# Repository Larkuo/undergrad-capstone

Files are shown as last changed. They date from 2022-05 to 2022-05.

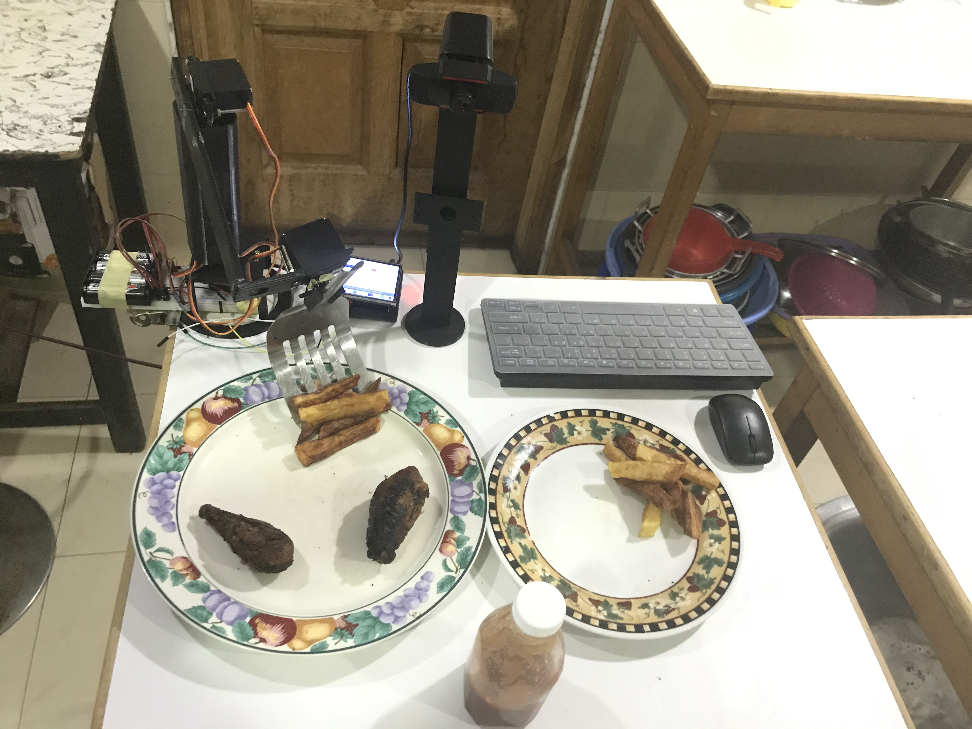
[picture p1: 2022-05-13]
Prototyping/Media/assembly_image.jpg

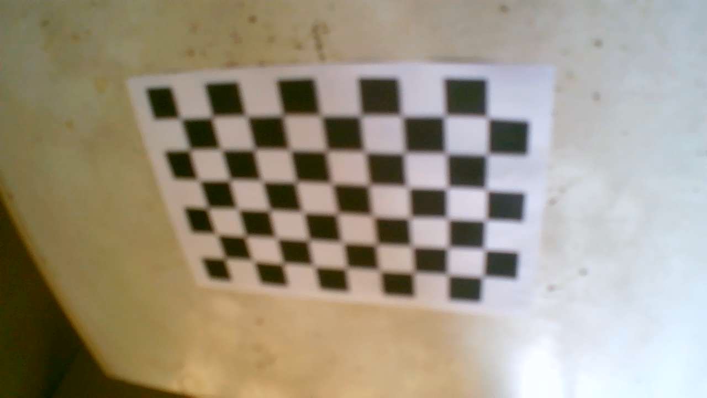
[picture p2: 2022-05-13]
Prototyping/Scripts/camera calibration images/WIN_20220427_16_50_19_Pro.jpg

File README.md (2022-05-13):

ENG401 - Engineering Capstone Project Seminar 2021-2022
============================

> This is a repository containing all my capstone files organized in the following folders.

├── .

    ├── README.md

    ├── Design                  # All files relevant to the design part of my project 

    │   ├── CAD Model           # Images & STL files from Onshape

    │   ├── Circuit Design      # Images & .fzz files from Fritzing

    ├── Model Training          # Files from the model training part of my project 

    │   ├── Data                # Images & Annotation files from LabelImg

            ├── Train           # 800 training images & corresponding annotaion files

            ├── Validate        # 200 validation images & corresponding annotaion files   

    │   ├── Notebooks           # All python notebooks used for training

    │   ├── Models              # All tflite models from training

    ├── Protoyping              

            ├── Scripts         # All python scripts used in the project

            ├── Media           # Prototype image & Demo video

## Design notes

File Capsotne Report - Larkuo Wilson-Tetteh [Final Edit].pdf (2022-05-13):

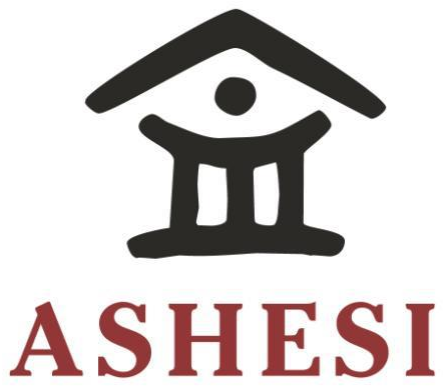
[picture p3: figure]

# ASHESI UNIVERSITY

DESIGN OF A LOW-COST ROBOTIC MANIPULATOR FOR FOOD

HANDLING

CAPSTONE PROJECT

### B.Sc. Computer Engineering

Larkuo Wilson-Tetteh

2022

ASHESI UNIVERSITY

DESIGN OF A LOW-COST ROBOTIC MANIPULATOR FOR FOOD

HANDLING

CAPSTONE PROJECT

### Capstone Project submitted to the Department of Engineering, Ashesi

### University College in partial fulfilment of the requirements for the award of

Bachelor of Science degree in Computer Engineering.

Larkuo Wilson-Tetteh

2022

i

DECLARATION

I hereby declare that this capstone is the result of my own original work and that no part of

it has been presented for another degree in this university or elsewhere.

Candidate’s Signature:

Candidate’s Name:

Larkuo Wilson-Tetteh

Date:

28/04/2022

I hereby declare that preparation and presentation of this capstone were supervised in

accordance with the guidelines on supervision of capstone laid down by Ashesi University

College.

Supervisor’s Signature:

Supervisor’s Name:

Dr. Stephen K. Armah

Date:

ii

Acknowledgements

To my supervisor, Dr. Stephen K. Armah whose encouragement and academic advice

helped me undertake this project.

iii

Abstract

Industry 4.0 improved production processes for many manufacturing processes however,

this change was not as pronounced in many service industries including the food service

industry. Considering the high cost of implementing technologies such as robotics, edge

computing and machine learning there are not many options for establishments such as

restaurants and fast-food places to also implement various parts of Industry 4.0 into their

services. With the growing consumer demand especially regarding dietary differences, it

has become more important for food service establishments to make their processes smarter

to keep up with the demand.

In this project, a low-cost, computer vision-controlled robotic manipulator is implemented

to assemble a custom plate of food without human assistance. This was achieved by

collecting and annotating 1000 images as well as training an object detection model with no

less than 90% average precision for each of the possible classes as well as an average recall

of 94.45% where there were no more than 10 objects in the image frame. A 3D printed

robotic manipulator was then assembled with servo motors, a Raspberry Pi, and a low-cost

web camera and the model, together with python scripts were then used to make real-time

detections while picking and dropping the food items from one plate to another within the

manipulator’s workspace.

iv

## Table of Contents

v

Chapter 1: Introduction

The food industry has not seen much adaptation of Industry 4.0 in its operations. With the ever-

increasing demand and variance in dietary preferences, it has become more important that food

service establishments begin to explore options to integrate smart technologies into their

kitchens. In this chapter of the project, a detailed background will be discussed followed by a

problem definition and a proposed solution. Finally, the objectives of the project will be

highlighted.

### 1.1 Background

Industry is an essential part of the global economy that produces goods through

mechanized and often automated processes. Industrialization has experienced multiple

technological cycles that enhanced processes throughout history with the most recent being

Industry 4.0. This cycle of the industrial revolution is changing the way industries manufacture

their products with the introduction of Internet of Things (IoT), Edge computing, Robotics,

Artificial Intelligence (AI) and machine learning into their manufacturing processes [1].

Essentially, Industry 4.0 describes the advent of smart factories which have predictive

maintenance, quicker responses, and more autonomously intelligent manufacturing

procedures.

While many industries have integrated many parts of Industry 4.0 into their operations,

the food production industry especially in customer-facing establishments has not seen much

change with regards to making their processes smarter. Commercial kitchens are one of such

customer-facing establishments and form a significant part of the industry. In commercial

kitchens, large quantities of are cooked and served in real-time daily and such kitchens are

typically found in places such as hotel restaurants, cafeterias, and fast-food establishments.

Like many other industries, commercial kitchens are designed to produce food quickly and repetitively without jeopardizing food quality and customer satisfaction.

### 1.2 Problem Definition

Commercial kitchens do a great job at serving multiple customers, these services

involve manned activities which are prone to error and inefficiency especially when exhaustion

sets in. Considering the cost of implementing traditional industrial automation and the growing

human population as well as an increasing variance in the dietary preferences of food

consumers [2] it has become more complex to use traditional industrial technologies to

automate processes in commercial kitchens unlike with other industries whose processes do

not involve as many customizations.

### 1.3 Proposed Solution

By means of smart, low-cost, and versatile technology commercial kitchens can begin

to implement parts of Industry 4.0 in their establishments to help them keep up with increasing

demand and ever-changing custom dietary requirements of the customers they serve. For this

project, the proposed solution would be to design and build an affordable robotic manipulator

that is smart and can identify different types of food items as well as assemble customizable

plates for customers.

### 1.4 Objectives 1.41 Main Objective

With the increasing demand placed on commercial kitchens and the need to keep up

with competitors, the aim of this project is to design and prototype an autonomous low-cost

robot that can assemble a meal with minimal human input. To reduce the need for human

interference or supervision, another important part of this project is to make the robot smart.

### 1.4.2 Specific Objectives

After establishing the primary objective of the project, which is to design a smart, low-cost robot to assemble a meal, some more specific objectives of this project are mentioned

subsequently.

1. Design a robotic arm that can pick and drop cooked food without significantly

altering the organoleptic properties of the food.

2. Design a robotic arm whose workspace is suitable for a kitchen workstation.
3. Train an object detection model that can correctly identify different food items and

kitchen utensils as well as their XYZ-positions in the workspace in real-time.

Chapter 2: Literature Review & Related Work

An important part of the engineering design process is reviewing existing literature and

projects to draw inspiration and identify gaps. In this chapter of the project, manipulator

dynamics will be studied along with important concepts in computer vision and object detection

such as image labelling and model evaluation metrics. Subsequently, similar existing projects

and papers that have been published will be mentioned to draw some inspiration for the solution

and identify some gaps.

### 2.1 Literature Review

### 2.1.1 Manipulator Dynamics

A manipulator’s kinematics can be described in two ways, forward kinematics, and

inverse kinematics. Forward kinematics are used to describe the position and orientation of the

robot’s end effector based on the angular displacement or velocity inputs from each joint of the

robot. Whereas inverse kinematics are used to calculate the value each joint variable given the

specific position and orientation of the end effector [3]. The Denavit-Hartenberg (D-H) method

[4] is a standard method used to derive the kinematics for a robotic manipulator for all robot

configurations and will be used in this paper.

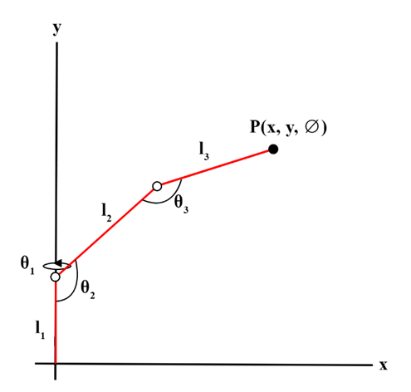
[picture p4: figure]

Figure 2.1: Labeled diagram of joint angles, link lengths, and end effector positions for a robotic manipulator

with 3 degrees of freedom.

From Figure 2.1,

P (x, y, ∅) = x, y position of end effector witℎ orentation ∅

li = lengtℎ of link i

θi = angle of rotation θ of link i

And, given a robot with 3 degrees of freedom (3-dof), like in figure 2.1, the forward kinematics

are,

x = l1cos θ1 + l2cos(θ1 + θ2

) + l3cos(θ1 + θ2 + θ3

) − − − (1)

y = l1 sin θ1 + l2 sin(θ1 + θ2) + l3 sin(θ1 + θ2 + θ3) − − − (2)

∅ = θ1 + θ2 + θ3 − − − (3)

While the inverse kinematics are,

θ1 = tan⁻¹

y
x

− − − (4)

θ2 = cos⁻¹

x

2 + y

2 + z

2 − l1

2
l2

2
2l1l2

− − − (5)

θ3 = sin⁻¹

∅
√x
2 + y

2 + ∅²

+ tan⁻¹

l2 sin θ2
l1 + l2 cos θ2

− − − (6)

### 2.1.2 Object Detection & Position Calculation

Object detection/recognition is a type of computer vision task where instances of

objects in an image or video frame are located [5] with details such as a bounding box, scale

of the object in the frame and the score of the prediction which describes how sure the model

is about the prediction. Algorithms that perform object detection tasks are often a result of

using machine learning to train the algorithm to detect the desired objects.

Measuring the performance of an object detection model is important before the model

is deployed into an application. Some performance metrics used to evaluate object detection

models include, Intersection over Union (IoU), Precision and Recall.

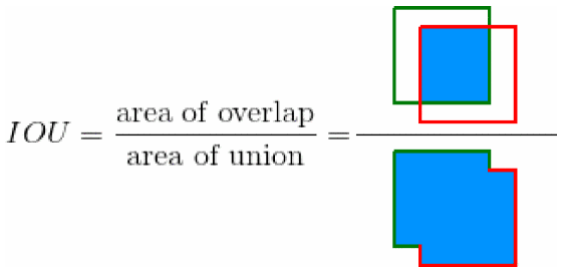
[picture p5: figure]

Figure 2.2: A graphical representation of the Intersection over Union (IoU) metric [6].

IoU is a metric that “measures the overlapping area between the predicted bounding box

and the ground-truth/actual bounding box divided the area of the union between them” as [6]

as demonstrated in Figure 2.2. Precision describes a model’s ability to only make correct

predictions. These include true positives and true negatives; true positives refer to correct

bound box detections where there are identifiable objects in the image/video frame while true

negatives refer to the absence of bound boxes where there are no identifiable objects in frame.

The metric recall assesses the model’s ability to find all existing bound boxes. [6].

### 2.2 Related Work & Gaps

2.2.1 Interpreting and Executing Recipes with a Cooking Robot (Bollini, Tellex,

Thompson, Roy & Rus)

In their paper “Interpreting and Executing Recipes with a Cooking Robot” Bollini,

Tellex, Thompson, Roy and Rus implemented a robot that reads plain text recipes for simple

dishes and executes them; one recipe at a time [7]. With the assumption that the robot had

access to a model of the kitchen, a set of labeled ingredients and the locations of tools such as a whisk or an oven the robot was initialized with a set of ingredients in labeled bowls laid out

on a table. It was also initialized with a set of natural language instructions describing how to

use the ingredients laid out to cook a specified dish. For instance, a group of ingredients which

include flour, butter, sugar, and eggs may be initialized together with instructions such as “Add

sugar and beat to a cream”. The robot also has a repertoire of basic actions which include

pouring and mixing ingredients. After parsing the plain text recipe to the robot, it performs the

inferred actions associated to the instruction using the PR2 Robot Manipulation Platform.

The PR2 Robot Manipulation Platform is a robot that was built by researchers at Willow

Garage and first released in February 2009 and made available for purchase in September the

next year; 2010 captured in Figure 2.3. It has two manipulators and runs on ROS (Robot

Operating System) which is an open-source robotics framework that allows communications,

message passing, remote procedure calls, among many other components [8].

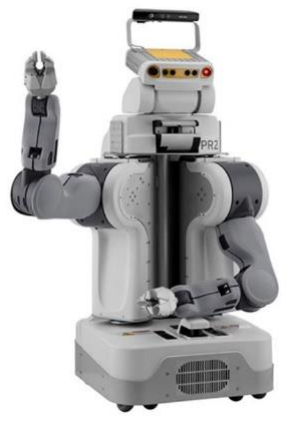
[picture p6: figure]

Figure 2.3: The Willow Garage PR2 Personal Robot 2 mobile manipulation platform used for the BakeBot

system [8].

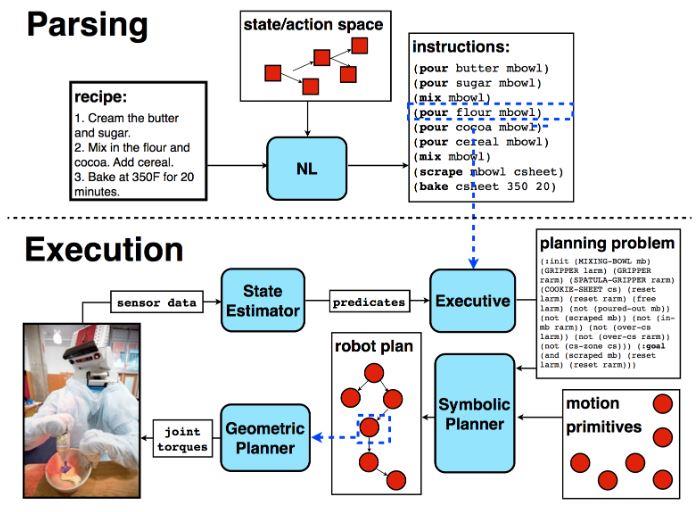
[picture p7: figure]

Figure 2.4: Architecture of the Bollini et al. BakeBot System that shows the progression from NL processing of

the plain text recipe to executing the task [7].

A graphical representation of the architecture of the cooking robot system by Bollini et

al. is shown in Figure 2.4.

To test their approach, the researchers experimented with their language processing

system and a database of 60 recipes to test instruction inference and a real-world demonstration

in a kitchen which had two work surfaces to test execution. After doing the real-world

experimentation 27 times, the researchers found that their defined basic motions enabled a

variety of recipes to be executed. They also discovered that their natural language system

worked well because for most instructions, it correctly inferred the corresponding action.

However, they also recorded an average runtime of 142 minutes from start to finish which was

far slower than the average human. In their tests, they also noted that the robot made many

more failures such as the end effector slipping of the oven door halfway through the opening

procedures.

An identifiable gap in Bollini et al.’s research paper is that the design focused heavily

on natural language processing. This resulted in the partial neglect of the design for the

hardware especially the end effector of the robot manipulators which resulted in mistakes. The

design and experimentation did not consider the different textures, hardness and sizes of the tools and ingredients that were used for the demonstration which affected the end effector’s

performance. Finally, the experiment did not mention how the robot adhered to kitchen hygiene

standards. Thus, the safety of the food for human consumption is not assessed.

### 2.2.2 A Methodology for the Selection for Industrial Robots in Food Handling. (Farah

Bader & Shahin Rahimifard)

Another paper that explored the robot selection process for the food industry is “A

methodology for the selection of industrial robots in food handling” by Bader and Rahimifard

[2]. The aim of this paper’s research was to discover a design methodology that makes it easier

for engineers and producers in the food industry to design flexible robots and suitable end

effectors that can handle food appropriately based on the foodstuff in the application. The

researchers also aimed at ensuring that the design process ensured that the organoleptic

properties of all foodstuffs handled by the selected robot was preserved. Bader and

Rahinmifard named their four-step process of selecting the appropriate robot for food handling

Food Industrial Robot Methodology (FIRM).

Step one of FIRM involves defining foodstuff by type and condition as well as the state

of the foodstuff under consideration.

- Foodstuff Type: Meat & Poultry, Seafoods, Fruits & Vegetables, Baked Goods

& Confectionaries, Dairy Derivatives or Others (e.g., grain like rice and powdered spices)

- Foodstuff Condition: Raw, Cooked or Frozen
- Foodstuff State: Whole or Segmented

Step two of the selection method further classifies food items by rigidity how hard or

soft the foodstuff is and deformability how easy it is to change visual and textural properties

the foodstuff when force is applied by the robot. In both classifications, foodstuff can be

described as follows.

- Deformability: Deformable or Non-Deformable
- Rigidity: Rigid, Semi-Rigid or Non-Rigid

These two classifications of foodstuff in this step creates six distinct groups which made

selection of the type of robot and suitable end effector easier.

Overall, this project excelled at creating a standard methodology for engineers who in

the future will work on industrial robots for food. However, a gap of this paper was that a

limited group of options were selected as options for handling the food. Again, though an

example of the FIRM procedure was demonstrated in the paper, the was no documented test to

give an idea of how effective this method is in real world food handling applications.

Chapter 3: Design

In this chapter of the project, the primary of objective will be to design an effective

food handling robotic manipulator and end effector that correctly identifies, locates, and picks

up food items to assemble a meal. For proof of concept, this project will focus on assembling

a plate of potato fries with a piece or more of chicken as well as a portion of ketchup where

requested.

### 3.1 Requirements

To achieve the objectives of this project, there are some functional and technical

requirements the manipulator needs to satisfy.

Functional Requirements:

1. A camera to enable computer vision-based object detection.
2. At least 3 degrees of freedom (3-dof) in the robotic arm to enable easy movement

in the workspace.

Technical Requirements:

3. An object detection model with at least 90% Average precision (AP) for each item

that needs to be detected.

4. An object detection model with at least 90% Average recall when there is a

maximum of 10 objects in the image/video frame.

### 3.2 Material Selection

In this section of the design chapter, materials including motors, a microcontroller and

a camera will be selected using weighted Pugh Matrixes which feature a datum as well as

comparison options for each part of the proposed solution.

### 3.2.1 Motors

In considering motor options for the manipulator, some significant requirements

included cost, feedback for closed loop control, power consumption, precision, torque, and

accuracy. These requirements are also weighted in the table below because requirements such

as cost, and feedback are more relevant to the project because the robotic manipulator needs to

be low cost and allow feedback for controls. However, requirements such as torque are

weighted less because all food items listed in the design overview weight less than 1 kilogram

(kg) since they will each be handled one at a time. The datum for this matrix was a DC motor

with the options being a servo motor and a stepper motor as shown in Table 3.1.

Table 3.1: Pugh matrix for the selection of motors with DC motor as datum

Criteria | Weight | DC Motor | Servo Motor | Stepper Motor
Low Cost | 3 | 0 | 0 | -
Feedback/Control | 4 | 0 | + | +
Power Consumption | 2 | 0 | 0 | -
Precision | 3 | 0 | + | +
Torque | 4 | 0 | + | +
Accuracy | 4 | 0 | + | +
Continuous Rotation | 5 | 0 | + | +
Total | | 0 | +20 | +15

In this selection, a servo motor was selected because like the datum, it is low cost

however, unlike the DC motor, it allows feedback and control without the need for an external

encoder. Finally, the servo motor had a higher score because it is accurate even at high speeds.

### 3.2.2 Manipulator Material

With the selection of the material most suitable for the manipulator, the criteria is focused on ease of cleaning, food safety, cost, heat resistance, durability, and humidity

resistance. This is because in typical kitchens where a solution of this type will be implemented,

there is high heat and humidity which are factors that cause corrosion and wear in some

materials. The datum for this selection is stainless steel; a material often used for kitchen

utensils and the options are aluminium, copper and polylactic acid (PLA).

Table 3.2: Pugh matrix for the selection of the manipulator material with stainless steel as datum

Criteria | Weight | Stainless Steel | Copper | Aluminium | Polylactic Acid (PLA)
Low Cost | 3 | 0 | - | + | +
Ease of cleaning | 3 | 0 | 0 | 0 | -
Food Safety | 5 | 0 | - | 0 | 0
Heat Resistance | 4 | 0 | - | - | +
Durability | 4 | 0 | - | - | -
Humidity Resistance | 4 | 0 | - | - | +
Total | | 0 | -20 | -14 | +4

From Table 3.2, the material with the highest score is polylactic acid (PLA) which was

scored higher than the other materials because of its low cost and food safety. Again, it is less

susceptible to corrosion in humid environments and does not conduct heat well which is

important for this project.

### 3.2.3 Microcontroller

For the selection of a microcontroller for this project, processing power was a very

important criteria because of the use of a camera in the design. This is because implementing

vision algorithms especially in real-time is computation heavy. Again, cost, power

consumption, and having enough GPIO pins were important to consider especially because of the motors required for this project.

Table 3.3: Pugh matrix for the selection of a microcontroller with Arduino Nano as datum

Criteria | Weight | Arduino Nano | Raspberry Pi 4 | ESP 32 | Tetrix Prizm
Low Cost | 3 | 0 | - | + | -
Processing Power | 5 | 0 | + | - | 0
GPIO Access | 5 | 0 | + | - | +
Power Consumption | 3 | 0 | - | + | -
Total | | 0 | +4 | -4 | -1

The Raspberry Pi 4 was selected in Table 3.1 because though it is slightly more

expensive than the datum, this microcontroller has USB ports compatible with many cameras.

The Raspberry Pi also has the best processing power compared to the datum and the other

options. This makes it the most appropriate for a computation heavy application such as object

detection. Again, the Raspberry Pi has enough pins to house all other components required for

the robotic manipulator.

### 3.2.4 Camera

For the selection of an appropriate camera, resolution, cost, field of view imaging rate

and suitable interconnect protocols were important criteria. Interconnect or interface standards

for cameras can be described as a codified identity for how a camera is connected to a computer

or micro-controller to allow easier and more effective use of vision as a technology. With this

selection, the datum was the Raspberry Pi Camera v2 with the rest of the selection options

being USB 2.0 camera as well as the Raspberry Pi NOIR camera. The criteria and the options

are shown in the Table 3.4.

Table 3.4: Pugh matrix for the selection of a camera with Raspberry Pi Camera v2 as datum

Criteria | Weight | Raspberry Pi Camera v2 | USB 2.0 Camera | Raspberry Pi NOIR Camera
Low Cost | 3 | 0 | + | 0
Interface Standard | 5 | 0 | + | 0
Power Consumption | 3 | 0 | - | 0
Field of View | 4 | 0 | + | 0
Resolution | 4 | 0 | 0 | 0
Imaging Rate | 4 | 0 | + | 0
Speed | 5 | 0 | + | 0
Total | | 0 | +18 | 0

Ultimately, the USB 2.0 camera was selected because it cost less, had a more common

interface standard as well as the camera standard having a larger bandwidth and wider range

for its field of view. Again, the selected camera is compatible with the selected microcontroller;

Raspberry Pi 4.

### 3.3 CAD Model

To model the movements of the manipulator prior to building the manipulator, a 3D

model was created using Onshape; a web-based computer aided design (CAD) software. The

model is a robotic manipulator with 3 motors: one for each degree of freedom. See Figure 3.1

and Figure 3.2.

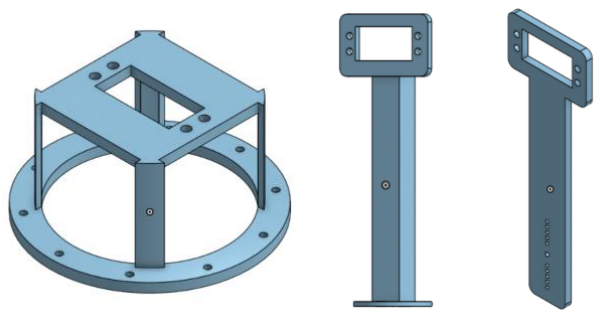
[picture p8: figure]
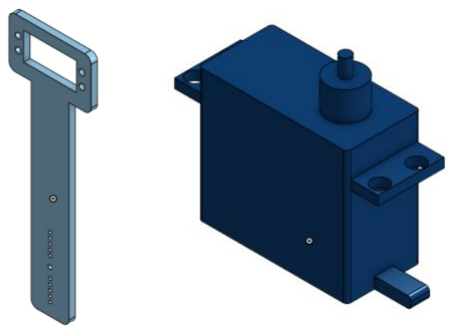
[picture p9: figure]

(a) | (b) | (c) | (d) | (e)

Figure 3.1: Diagram of parts for the 3D model of the manipulator (a) Link 1 (b) Link 2 (c) Link 3 (d) Base (e)

| | Servo Motor

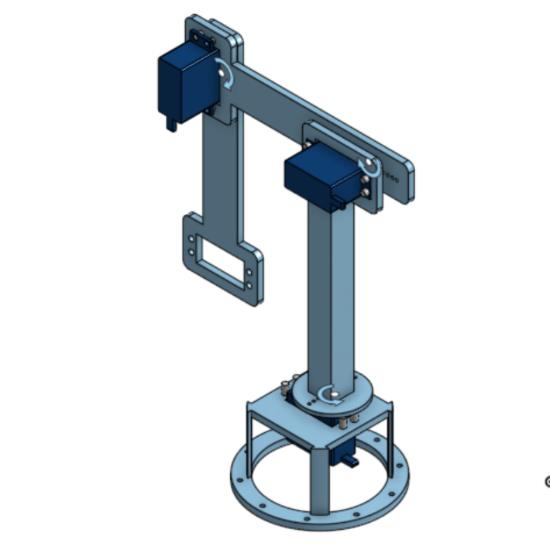
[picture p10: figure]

Figure 3.2: Image of manipulator assembly CAD model

### 3.4 Electrical Circuit

Figure 3.3 shows how the electrical and electronics parts of the robot manipulator will

be connected. The connections include 4 servo motors, a Raspberry Pi, a USB camera plugged

into the Raspberry Pi and 2 power supplies; one for the Raspberry Pi and another for the servo

motors.

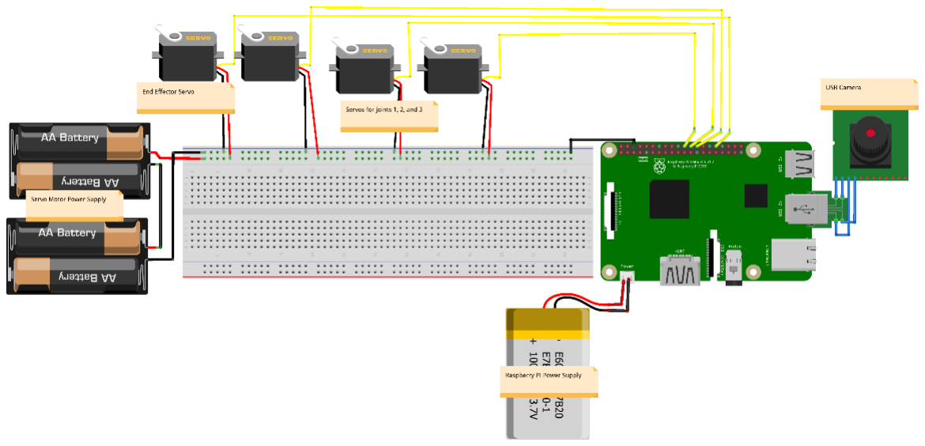
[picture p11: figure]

Figure 3.3: Circuit diagram of electronic connections for a 3 DOF manipulator in Fritzing

Chapter 4: Data Collection & Model Training

In this chapter of the project, details about collecting the images, processing the images,

and labelling the images will be discussed. Setting up the training environment and other

required details as well as the process of training the object detection model will be highlighted.

### 4.1 Image Collection & Labeling

### 4.1.1. Image Collection

One of the most important parts of training any machine learning model is the process

of collecting the data. For this project, a USB camera was connected to a computer at a height,

30 cm from the kitchen worktable as shown in Figure 4.1.

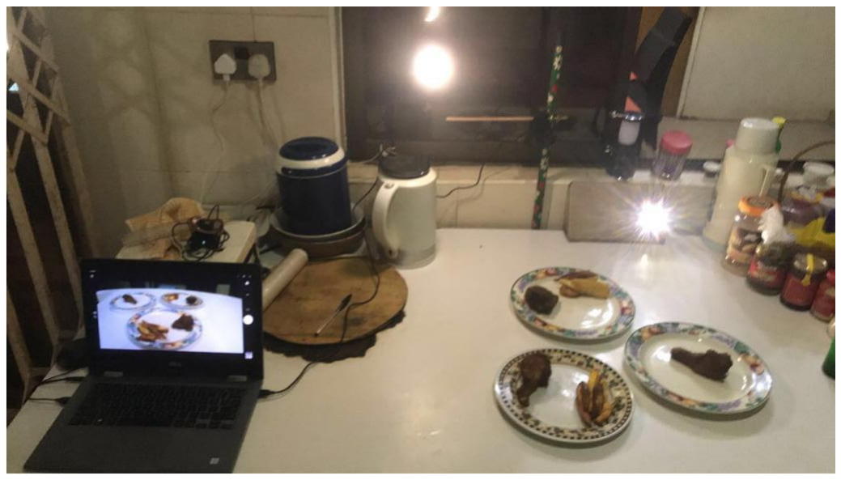
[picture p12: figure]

Figure 4.1: An image of the data collection setup with the laptop and camera

With the computer and camera setup, 1000 images were taken: each with a resolution

of 640 pixels x 320 pixels. Images were taken in batches of 5 with variations which included

changing the orientation of items, reducing the amount of light, and moving objects in and out

of the image frame. Some samples of the images are shown in Figure 4.2.

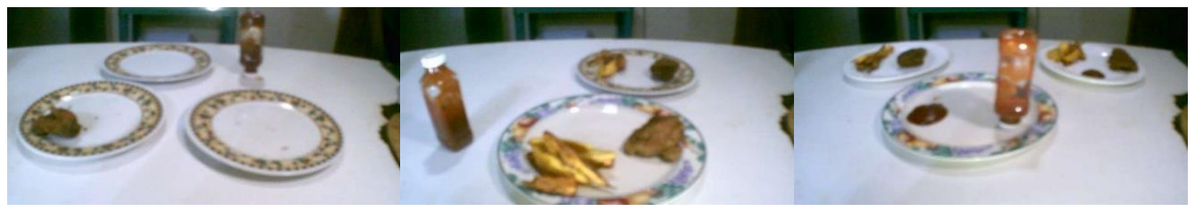
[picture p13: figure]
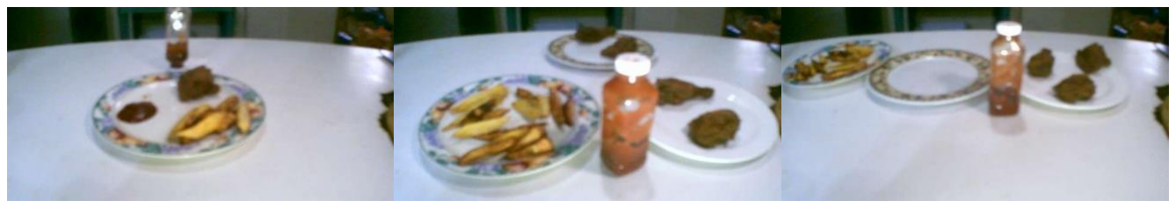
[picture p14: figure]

Figure 4.2: Sample images from data collection

### 4.1.2. Image Processing & Labeling

Following the collection of the images, a python script was written to rename the

images with numbers in order to improve the coherence of the file naming and make it easier

to associated related annotation files. Each file was named img-<number> where the number

count began from 0 and ended at 999.

With a more coherent naming format for the images, the images were labelled with

LabelImg: a python-based graphical tool that allows users to create bound boxes around objects

in an image and save the boxes and labels as a preferred file format [10] depicted in Figure 4.3

below. Through the labelling process, bound boxes were drawn around each item in each image

and labelled as one of the following five classes/labels: ketchup bottle, ketchup portion, potato

fries, chicken, and empty plate.

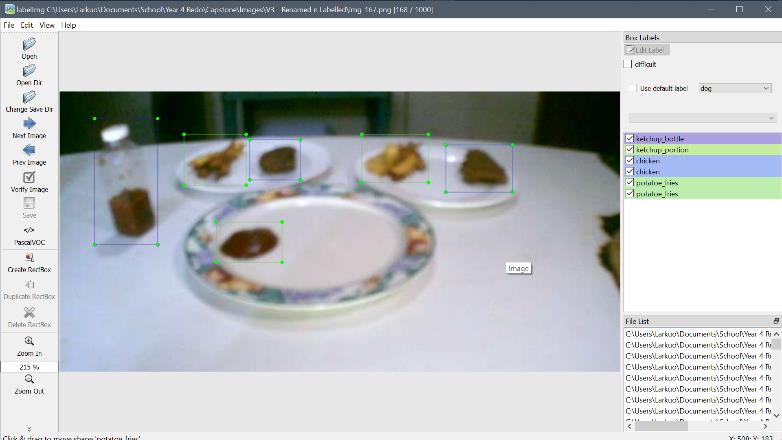
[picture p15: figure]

Figure 4.3 A screengrab of the LabelImg application while images were being labelled

Labeling all 1000 images resulted in a total of 4301 individual bound boxes with the average

number of bound boxes per image being 4. In the bar chart below, the distribution of the classes

for the bound boxes is shown.

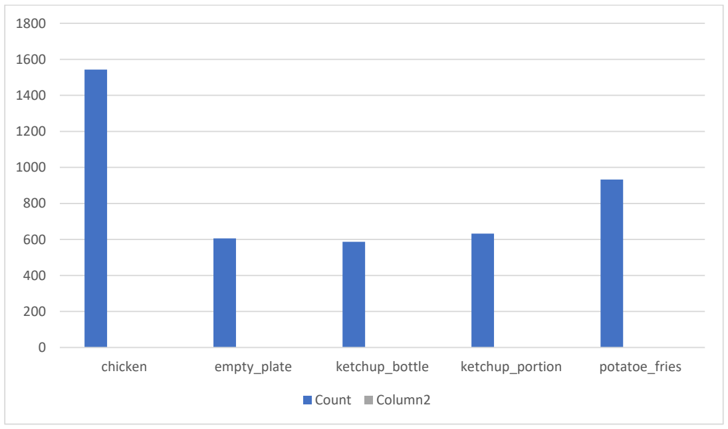
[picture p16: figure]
chicken; empty_plate; ketchup_bottle; ketchup_portion; potatoe_fries; Count; Column2

Figure 4.4: A bar chart of the count of the bound box classes

### 4.3 Model Training

Training the model for this project was done in Gradient; a web-based machine-learning

and deep-learning resource by the company Paperspace that offers python notebooks as well

as CPUs and GPUs for training machine learning models. Before training the model, a python

script was used randomize the images and split the data into an 80:20 ratio for training and

validating the object detection model.

Tensorflow is an open-source software library developed by Google researchers that

allows users to build, train and evaluate machine learning models and applications [11].

Tensorflow Lite is a version of Tensorflow that allows machine learning applications to be

deployed on devices with more limited memory and storage such as mobile devices,

microcontrollers as well as other edge devices.

To train the model, the EfficientDet computer vision architecture was used.

EfficientDet is an object detection architecture which uses multiple optimizations as well as a

compound scaling method which allows a single model uniformly scale the resolution, depth

and width of images regardless of the backbone [12]. In the Tensorflow Lite library, there are

5 architectures based on EfficentDet; EfficientDet-Lite0, EfficientDet-Lite1, EfficientDet-

Lite2, EfficientDet-Lite3 and, EfficientDet-Lite4. Where, EfficientDet-Lite0 has the lowest

latency (146 ms) and EfficientDet-Lite4 has the highest latency (1886 ms). For this project,

Efficient-Lite0 was chosen to train the model because the model was going to be used to make

predictions in real-time hence, minimal latency was important.

With all the training data and required libraries saved into the python notebook’s

workspace, the model was trained for 100 cycles (epochs) with a batch size of 10 per step of

each epoch. At the end of 100 epochs the model was saved in the “tflite” format and evaluated

to verify that it met the requirements.

Chapter 5: Model Results & Prototyping

In the model results and prototyping chapter of the project, an overview of the

prototyping process will be outlined. The results of evaluating the object detection model will

also be discussed together with the process of assembling the manipulator and using python

scripts to make real-time object detections while using manipulator kinematics to move the

robotic manipulator.

### 5.1 Overview

After training the model and evaluating it, the model was downloaded unto the

Raspberry Pi and used to make predictions. The predictions were then used to pick and drop

food items from one point of the kitchen workbench to another point. In this chapter, the results

of the model’s evaluation will be discussed alongside assembling the robot and using the

model’s predictions and python scripts to move the manipulator servos to pick and drop food

items.

To using the manipulator prototype and the detection model, the sequence of events are

shown in the flow chart; see Figure 5.1.

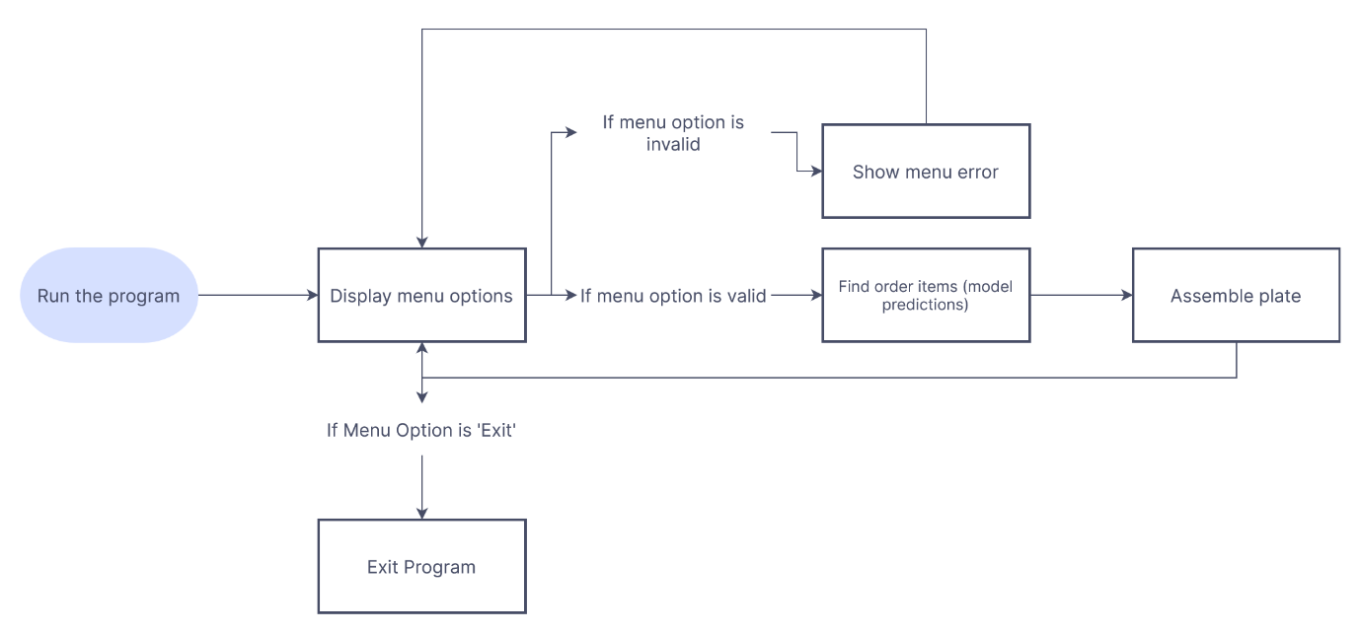
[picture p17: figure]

Figure 5.1: A flow chart demonstrating the sequence of events for prototyping

### 5.2 Model Results

An important part of the engineering design process is reviewing existing literature and

projects to draw inspiration and identify gaps. In this chapter of the project, manipulator

dynamics will be studied along with important concepts in computer vision and object detection

such as image labelling and model evaluation metrics. Subsequently, similar existing projects

and papers that have been published will be mentioned to draw some inspiration for the solution

and identify some gaps.

After saving and evaluating the detection model, the average recall (AR) for predictions

with a maximum number of 10 bound boxes per frame was 94.45%. The average precision

(AP) of each class after the model was evaluated is shown in Table 5.2.

Table 5.2: Table of Average Precision for each Object class/label

Class | chicken | ketchup_portion | ketchup_bottle | potatoe_fries | empty_plate
AP (%) | 92.18 | 93.01 | 91.52 | 93.43 | 92.74

On saving the model to the Raspberry Pi, and setting a score threshold of 85%, the

model made predictions as shown in Figure 5.2 and Figure 5.3.

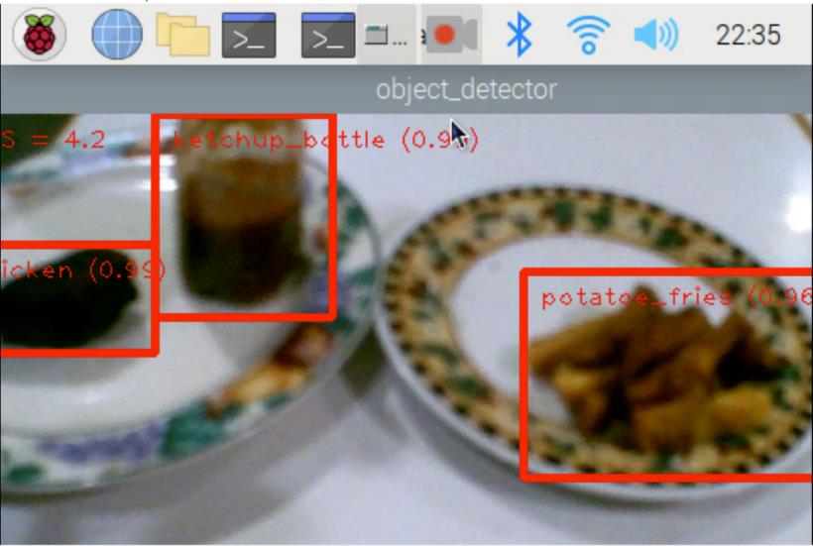
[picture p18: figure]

Figure 5.2: A screen grab of the Raspberry Pi while the model was in use

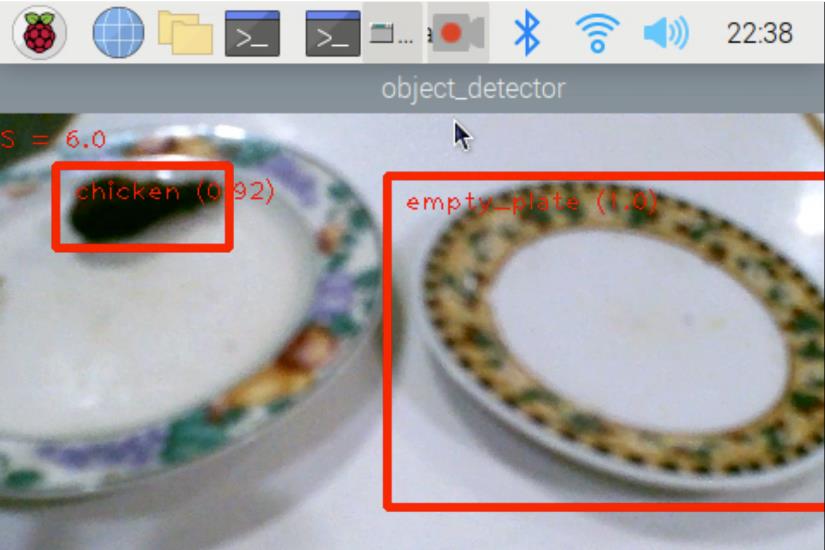
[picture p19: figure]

Figure 5.3: A screen grab of the Raspberry Pi while the model was in use

### 5.3 Assembling the Manipulator

To prototype the solution proposed in Chapter 1, the parts of CAD model were 3D

printed with a PLA (polylactic acid) filament. Following the print, the robotic manipulator was

assembled using screws to attach the motors to the printed parts. All other electronics were

subsequently assembled and connected as shown at the end of the design chapter. An image of

the assembled model is shown Figure 5.4.

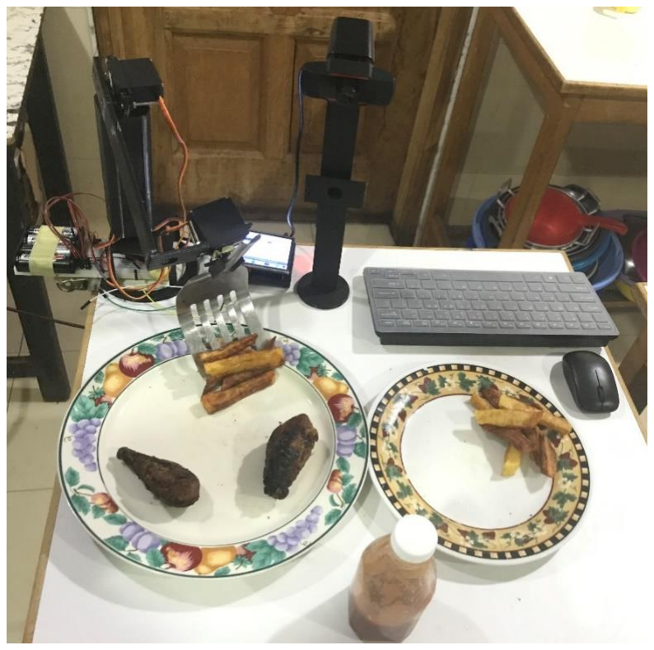
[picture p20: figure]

Figure 5.4: An image of the assembled manipulator

### 5.4 Real-time detections & Manipulator movements

Using the inverse kinematic equations of a 3-dof robotic manipulator discussed in the

literature review, functions were written in python to get the position of an object, compute the

joint angles and move the end effector to the correct position using the servo motors.

The model detected objects with the output being bound boxes, labels and scores.

However, for the manipulator to have moved to the food item, it was important to convert the

bound boxes to real world coordinates.

First, the centre of the bound boxes for the detections were computed as follows given

a bound box [x min, y min, x max, y max].

bound box centre x, xc =

x min + x max
2

bound box centre y, yc =

y min + y max
2

Next, the centre point was converted to a 3D point [9]. To do this, OpenCV was used

to calibrate the camera in order to get the intrinsic properties of the camera; focal length (fx, fy)

and optical centre in pixels (cx, cy). Then, the x, y and z coordinates of the objects were

computed as shown in the subsequent equations.

z =

fx ∗ known widtℎ
x max − x min

x =

(xc − cx

) ∗ z
fx

y =

(yc − cy) ∗ z
fy

Chapter 6: Conclusion & Future Works

### 6.1 Conclusion

By means of the growing variation in dietary demands of customers, it has become

more important for food service establishments to make their processes smarter. In this project,

the aim was to explore a low-cost solution to this problem by using a robotic manipulator with

a camera. With objectives including high precision for an object detection model to identify

food items, this project demonstrated that affordability is feasible for building smart solutions

and applying more Industry 4.0 technologies to food handling.

### 6.2 Future Works

Moving forward, it will be beneficial to invest more time into finding more cost-

effective methods to deploy computer vision models for food related applications. It will also

be useful to build embedded systems that can be integrated into existing commercial kitchen

electronics instead of building new technology. Finally, for future work, exploring the use of

sensors besides cameras could be valuable to maintaining safety in commercial kitchens while

making Industry 4.0 more accessible to the food service industry especially through cost.

References

[1] H. Lasi, P. Fetteke, T. Feld and, M. Hoffmann, (2014) “Industry 4.0”, Business & Information Systems Engineering. Vol 6: Iss. 4, pp. 239-242. Available: https://aisel.aisnet.org/bise/vol6/iss4/5
[2] B. Farah and S. Rahimifard, (2020) “A Methodology for the Selection of Industrial Robots for Food Handling”, Innovative Food Science & Emerging Technologies. Vol 64: Iss. 3, 102379. Available: https://doi.org/10.1016/j.ifset.2020.102379
[3] G. Chen, and S. Liu, “Dynamics and Control of Robotic Manipulators with Contact and Friction,” in Robotic Manipulators, 1st ed. West Sussex, UK: Wiley, 2019, ch. 1&2, pp. 9-39.
[4] J. Denavit and, R. S. Hatrtenberg, (1955). “A Kinematic Notion for Lower-Pair Mechanisms based on Metrics”, Trans.\ ASME E Journal of Applied Mechanics. Vol 22, pp. 215-221. Available: https://doi.org/10.1115/1.4011045
[5] Y. Amit and, P. Felzenszwalb, (2014, January 10) “Object Detection”. University of Chicago. Available: htttps://doi.org/10.1007/978-0-387-31439-6_660
[6] R. Padilla, S. L. Netto, and, E. A. B. da Silva, (2020, July 21) “A Survey on Performance Metrics for Object-Detection Algorithms”, 2020 International Conference on Systems, Signals and Image Processing (IWSSIP). pp. 237-242. doi: 10.1109/IWSSIP48289.2020.9145130
[7] M. Bollini, S. Tellex, T. Thompson, N. Roy & D. Rus, (2013), “Interpreting and Executing Recipes with a Cooking Robot”, Experimental Robotics. Vol 88, pp. 481-
495. Available: https://doi.org/10.1007/978-3-319-00065-7_33
[8] M. Wise, M. Ferguson, D. King, E. Diehr and, D. Dymesich, (2016), “Fetch & Freight: Standard Platforms for Service Robot Applications”, Fetch Robotics Inc. Available: https://fetchrobotics.borealtech.com/wp-content/uploads/2019/12/Fetch-and-Freight-Workshop-Paper.pdf
[9] J. Weng, P. Cohen and, M. Herniou. (1992) “Camera calibration with distortion models and accuracy”, IEEE Transactions on Pattern Analysis and Machine Intelligence. Vol 1: Iss. 10. pp. 965-980.
[10] L. Tzuta, (2021) “LabelImg”. Available at: https://github.com/tzutalin/labelImg
[11] M. Abadi, et. al. (2016) “Tensorflow: A system for large-scale machine learning”, 12th USENIX Symposium on Operating Systems Design and Implementation (OSIDI 16). pp. 265-283. Available at https://research.google/pubs/pub45381/
[12] T. Mingxing, P. Ruoming and, V. Le Quoc. (2020) “EfficientDet: Scalable and Efficient Object Detection”. Google Research, Brain Team. Available: https://arxiv.org/pdf/1911.09070.pdf

Appendix

### 7.1 Python Scripts

### 7.1.1 rename_img.py

import os

def rename_images(folder):
for count, filename in enumerate(os.listdir(folder)): newname = f"img-{str(count)}.png"
img_path = f"{folder}/{filename}"
newname = f"{folder}/{newname}"

os.rename(img_path, newname)
print(f"file[{str(count)}] renamed from {filename} to {newname}")

### 7.1.2 robot.py

from servo import Servo
from time import sleep
from math import acos, asin, atan, degrees, sin, cos, sqrt

class Robot:
def __init__(self, servo1_pin, servo2_pin, servo3_pin, link1, link2, link3): self.servo1 = Servo(servo1_pin, 50)
sleep(1)
self.servo2 = Servo(servo2_pin, 50)
sleep(1)
self.servo3 = Servo(servo3_pin, 50) sleep(1)
self.cur_pos = [0, 0, 0] # x, y, z self.link1 = link1
self.link2 = link2
self.link3 = link3

def returnToOrigin(self):
self.servo1.moveAngle(1)
sleep(1)
self.servo2.moveAngle(1)
sleep(1)
self.servo3.moveAngle(1)
sleep(1)

def moveToPosition(self, x, y, z): # set current position to x, y, z self.cur_pos = (x, y, z)

# compute angle for joint 1 theta1 = degrees(atan(y/x))

# compute angle for joint 2

a = (x^2) + (y^2) + (z^2) - (self.link1^2 * self.link2^2) b = 2 * self.link1 * self.link2
theta2 = degrees(acos(a/b ))

# compute angle for joint 3

r = sqrt( (x^2) + (y^2) + (z^2) )
c = self.link2 * sin(theta2)
d = self.link1 + (self.link2 * cos(theta2)) theta3 = degrees(asin(z/r) + atan(c/d))

# move robot to position x, y z self.servo1.moveAngle(theta1) sleep(1)

self.servo2.moveAngle(theta2) sleep(1)
self.servo3.moveAngle(theta3) sleep(1)

# return to robot's original position self.returnToOrigin()

### 7.1.3 camera.py

import sys
import cv2
from object_detector import ObjectDetector
from object_detector import ObjectDetectorOptions def run(model, camera_id, width, height, num_threads): # Start capturing video input from the camera
cap = cv2.VideoCapture(camera_id) cap.set(cv2.CAP_PROP_FRAME_WIDTH, width) cap.set(cv2.CAP_PROP_FRAME_HEIGHT, height)

# Visualization parameters

text_color = (0, 0, 255) # red font_size = 1
font_thickness = 1

# Initialize the object detection model options = ObjectDetectorOptions( num_threads=num_threads,

score_threshold=0.9,
max_results=3,
enable_edgetpu=False)
detector = ObjectDetector(model_path=model, options=options)

# Continuously capture images from the camera and get predictions while cap.isOpened():

success, image = cap.read()
if not success:
sys.exit('ERROR: Unable to read from webcam. Please verify your webcam settings.')

image = cv2.flip(image, 1)

# Run object detection estimation using the model. rgb_image = cv2.cvtColor(image, cv2.COLOR_BGR2RGB) detections = detector.detect(rgb_image)

# Draw bound boxes on input image

for detection in detections:
category = detection.categories[0]

xmin = detection.bounding_box.left ymin = detection.bounding_box.top xmax = detection.bounding_box.right ymax = detection.bounding_box.bottom

start = xmin, ymin
end = xmax, ymax

cv2.rectangle(image, start, end, text_color, 3)

### 7.1.4 object.py

import math

class Object:
def __init__(self, name='object', bnd_box=[0,0,0,0], score=0.5): self.name = name
self.bnd_box = bnd_box
self.score = score
x = (self.bnd_box[0] + self.bnd_box[2]) // 2 y = (self.bnd_box[1] + self.bnd_box[3]) // 2
self.center = [x, y]

def get_object_position(self, known_width=10): # known width in cm x = self.center[0]
y = self.center[1]

width_pix = self.bnd_box[2] - self.bnd_box[0] # xmax - xmin # camera parameters after calibration with open cv
# x & y focal lengths of the camera

fx = 1.01228658 * math.exp(3)
fy = 1.01955224 * math.exp(3)

# x & y optical center points of the camera cx = 6.51698659 * math.exp(2)

cy = 3.83238934 * math.exp(2)

z_world = (fx * known_width) / (width_pix)

x_world = ((x-cx)*z_world)/fx
y_world = ((y-cy)*z_world)/fy

return x_world, y_world, z_world

### 7.1.5 menu.py

from camera import run
from robot import Robot
from object import Object
from time import sleep
import cv2
import RPi.GPIO as GPIO

def get_menu_option():
try:
menu_msg = menu_msg_intro

for optn in menu_optns:
menu_msg+= optn

print(menu_msg)
menu_option = input()

return int(menu_option)
except Exception as e:
print(f'Input Error: {e}')

def get_chicken():
name = 'chicken'
detections = run(model_path, camera_id, frame_width, frame_height, num_threads)
for d in detections:
category = d.categories[0]

xmin = d.bounding_box.left ymin = d.bounding_box.top
xmax = d.bounding_box.right ymax = d.bounding_box.bottom

if category.label == name:
break
obj = Object(name, [xmin,ymin,xmax,ymax], round(category.score, 2)) x,y,z = obj.get_object_position(12)
Robot1.moveToPosition(x, y, z)
sleep(1)
Robot1.returnToOrigin()

def get_chicken():
name = 'chicken'
detections = run(model_path, camera_id, frame_width, frame_height, num_threads)
for d in detections:
category = d.categories[0]

xmin = d.bounding_box.left ymin = d.bounding_box.top
xmax = d.bounding_box.right ymax = d.bounding_box.bottom

if category.label == name:
break
obj = Object(name, [xmin,ymin,xmax,ymax], round(category.score, 2)) x,y,z = obj.get_object_position(12)
Robot1.moveToPosition(x, y, z)
sleep(1)
Robot1.returnToOrigin()

def get_ketchup_bottle():
name = 'ketchup_bottle'
detections = run(model_path, camera_id, frame_width, frame_height, num_threads)
for d in detections:
category = d.categories[0]

xmin = d.bounding_box.left ymin = d.bounding_box.top
xmax = d.bounding_box.right ymax = d.bounding_box.bottom

if category.label == name:
break
obj = Object(name, [xmin,ymin,xmax,ymax], round(category.score, 2)) x,y,z = obj.get_object_position(12)
Robot1.moveToPosition(x, y, z)
sleep(1)
Robot1.returnToOrigin()

def assemble_plate():
option = get_menu_option() try:
while option != 7:
print(f'Starting plate assembly for option {menu_optns[option-1]}') if option == 1:
get_chicken()
elif option == 2:
get_potato_fries()
elif option == 3:
get_chicken()
get_ketchup_bottle()
elif option == 4:
get_potato_fries()
get_ketchup_bottle()
elif option == 5:
get_chicken()
get_potato_fries()
elif option == 6:
get_chicken()
get_potato_fries()
get_ketchup_bottle()
else:
print('Invalid option selected, try again\n') print('-------------------------------------------\n') option = get_menu_option()

print('Exiting Plate Assembly Script')
except Exception as e:
print(f'Menu Error: {e}')

### 7.2 Training Notebook

The | python | notebook | where | the | model | was | trained | can | be | found

https://console.paperspace.com/larkuo/notebook/rncthelresxae8i.

### 7.3 Images and Annotation Files

All | training | files | (images | and | annotations) | can | be | found

https://drive.google.com/drive/folders/1YtVByGrUQsYqhoLIwHVkW40qeQBHMYY0?usp

=sharing. (https://drive.google.com/drive/folders/1YtVByGrUQsYqhoLIwHVkW40qeQBHMYY0?usp=sharing)

All | validation | files | (images | and | annotations) | can | be | found

https://drive.google.com/drive/folders/10a4BlyLBIEDgVBWC_ttRKQXRhKuF2iKj?usp=sh

aring. (https://drive.google.com/drive/folders/10a4BlyLBIEDgVBWC_ttRKQXRhKuF2iKj?usp=sharing)

### 7.4 CAD Model

The | CAD | assembly | can | be | found | on | Onshape | from
https://cad.onshape.com/documents/f5559b3a8d1dfa5452cc9610/w/2c8fd2f6f4ca79821d800561/e/9566d325d534fbadf0bd8f40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
80. (https://cad.onshape.com/documents/f5559b3a8d1dfa5452cc9610/w/2c8fd2f6f4ca79821d800561/e/9566d325d534fbadf0bd8f40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)

### 7.5 GitHub Link

Find | all | scripts, | notebooks, | data | and, | CAD | Model | on | GitHub | at
https://github.com/Larkuo/undergrad-capstone.

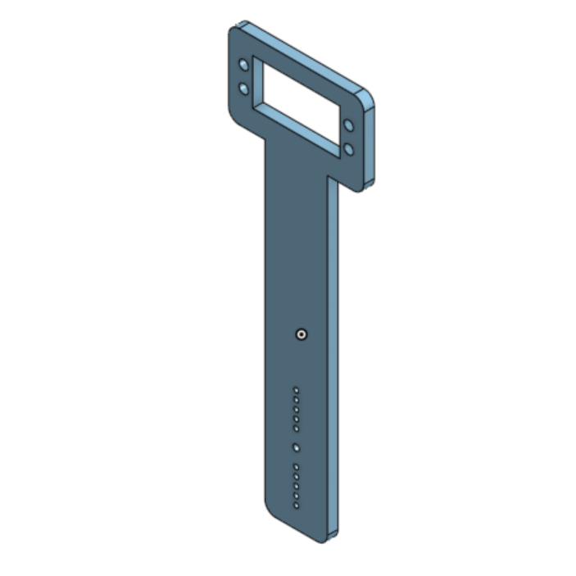
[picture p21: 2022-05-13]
Design/CAD Model/cad images/cad_link_2.png

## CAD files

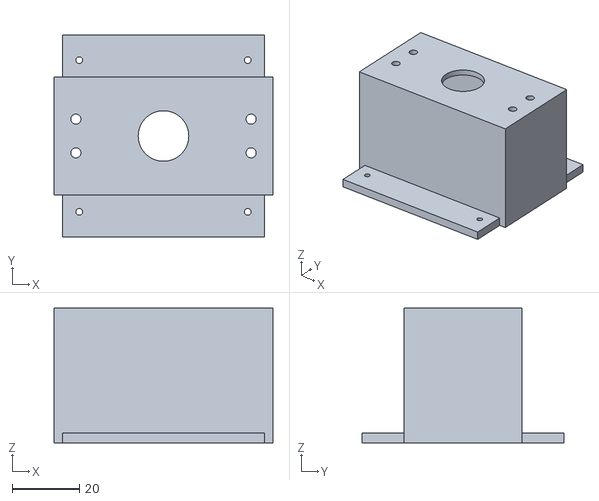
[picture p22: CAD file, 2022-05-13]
Design/CAD Model/Parts to Print - V3/Base Main.stl
65.0 x 60.0 x 40.0

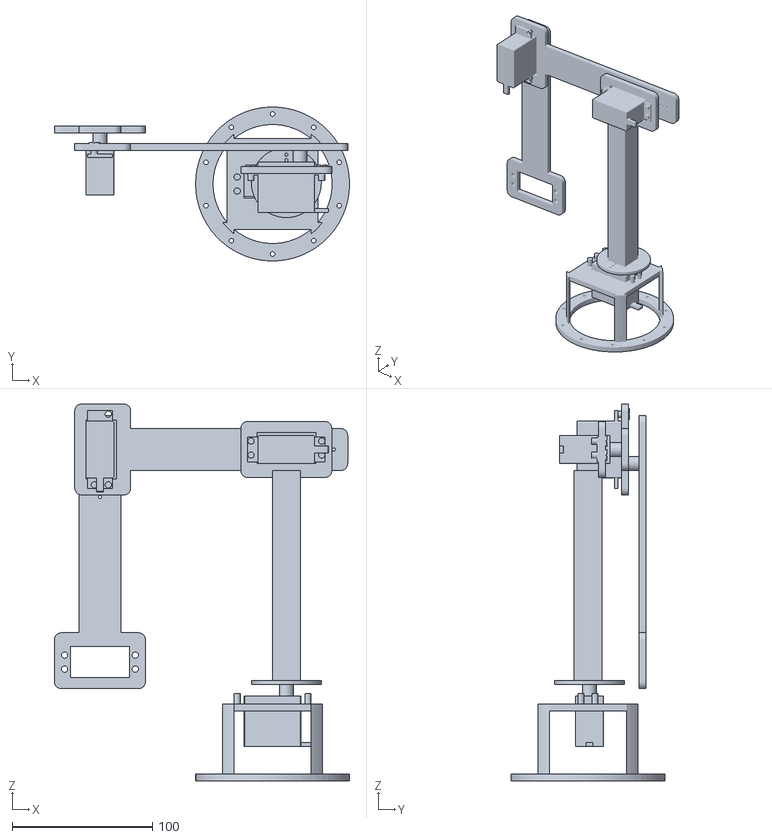
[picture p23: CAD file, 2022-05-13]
Design/CAD Model/CAD Final/Arm Assembly.stl
210.8 x 109.8 x 269.2

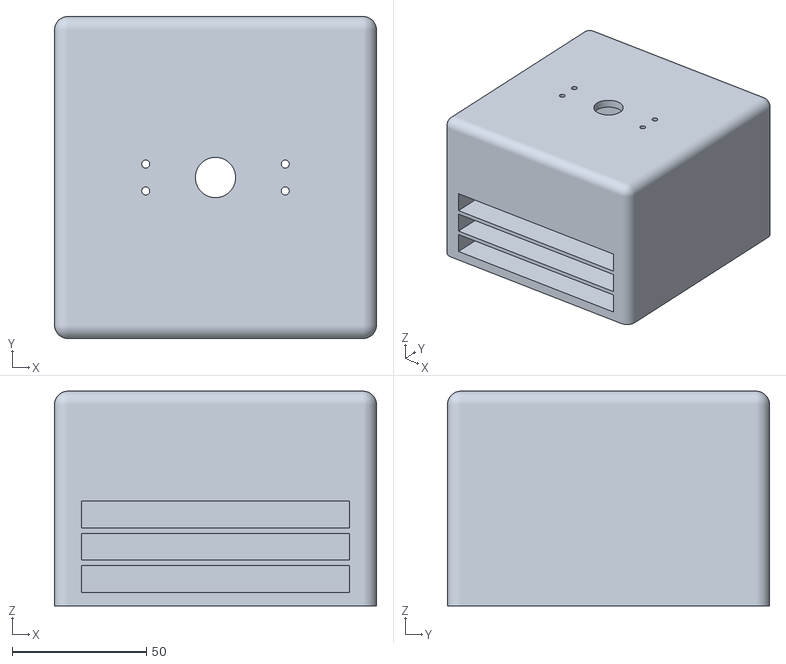
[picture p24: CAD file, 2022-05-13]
Design/CAD Model/Parts to Print/Arm/Base Main.stl
120.0 x 120.0 x 80.0

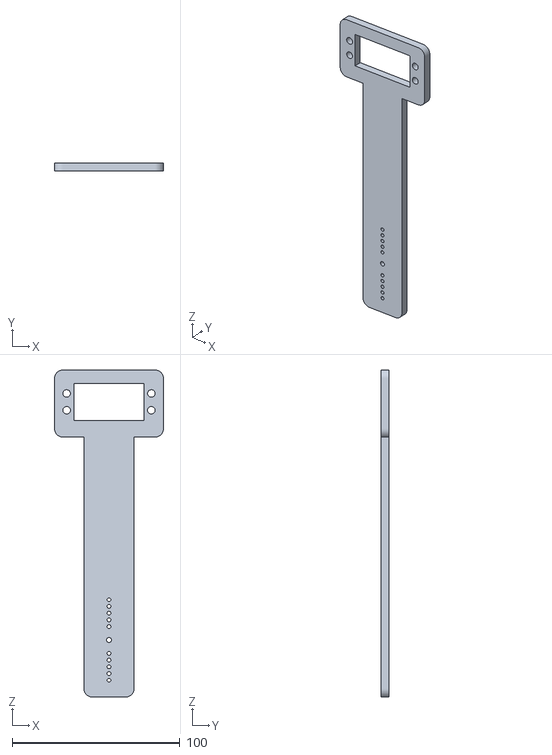
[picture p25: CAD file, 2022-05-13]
Design/CAD Model/CAD Final/Link 3.stl
65.0 x 5.00 x 195.0

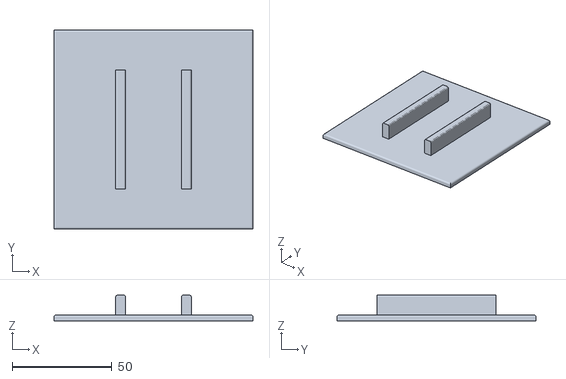
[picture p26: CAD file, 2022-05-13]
Design/CAD Model/Parts to Print/Arm/Base Slab (Breadboard).stl
100.0 x 100.0 x 13.0

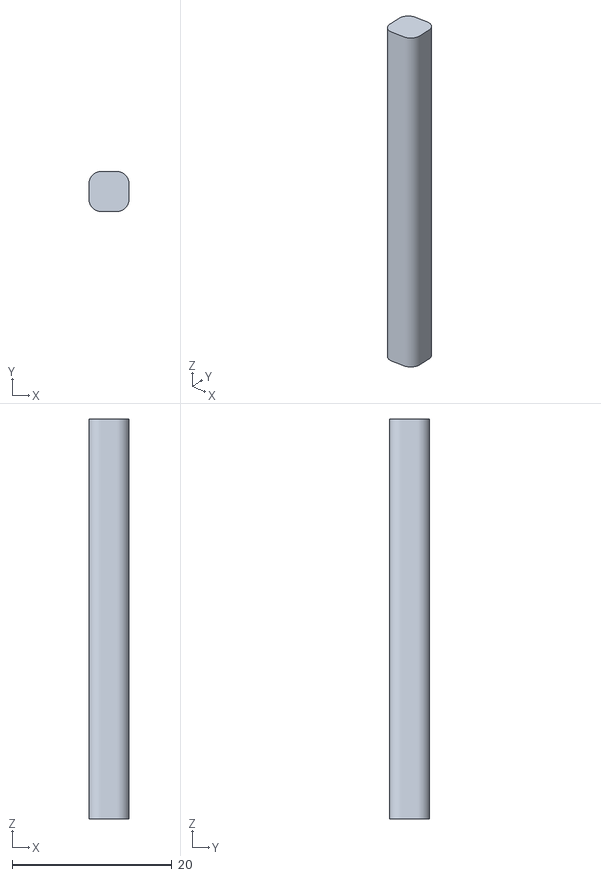
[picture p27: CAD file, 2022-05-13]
Design/CAD Model/Parts to Print/Camera Stand/Camera Base Pin.stl
5.00 x 5.00 x 50.0

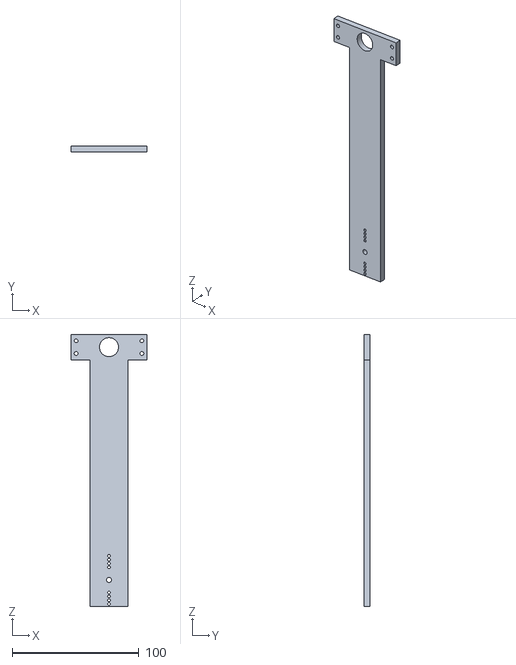
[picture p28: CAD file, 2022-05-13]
Design/CAD Model/Parts to Print - V3/Link 3.stl
60.0 x 5.00 x 215.0

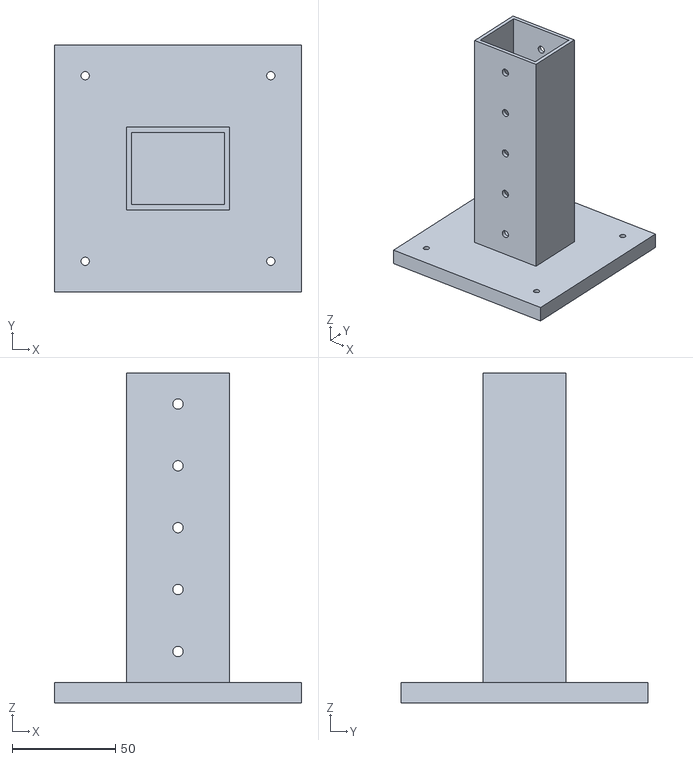
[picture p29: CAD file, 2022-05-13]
Design/CAD Model/Parts to Print/Camera Stand/Camera Base A.stl
120.0 x 120.0 x 160.0

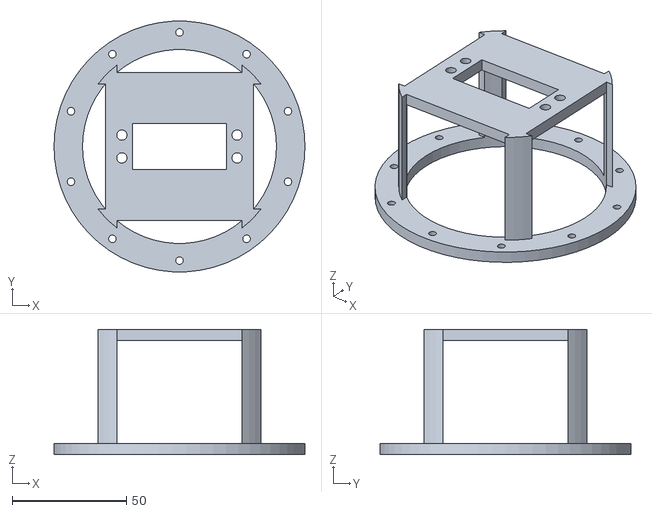
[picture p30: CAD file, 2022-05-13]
Design/CAD Model/CAD Final/Base.stl
110.0 x 109.8 x 55.0

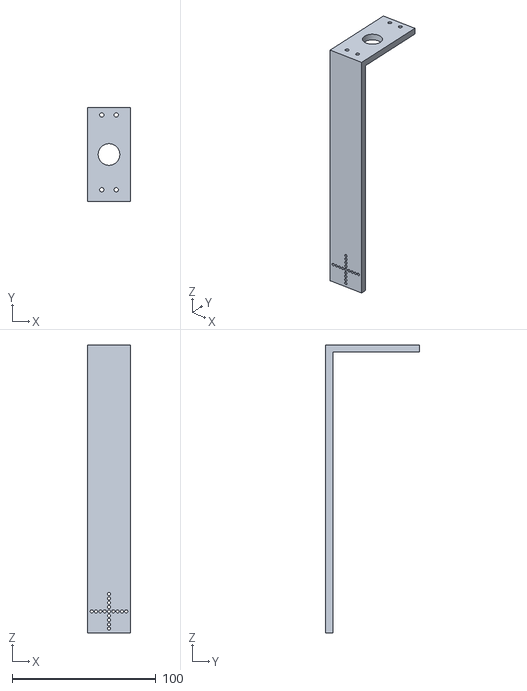
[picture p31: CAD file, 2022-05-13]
Design/CAD Model/Parts to Print - V3/Link 2.stl
30.0 x 65.0 x 200.0

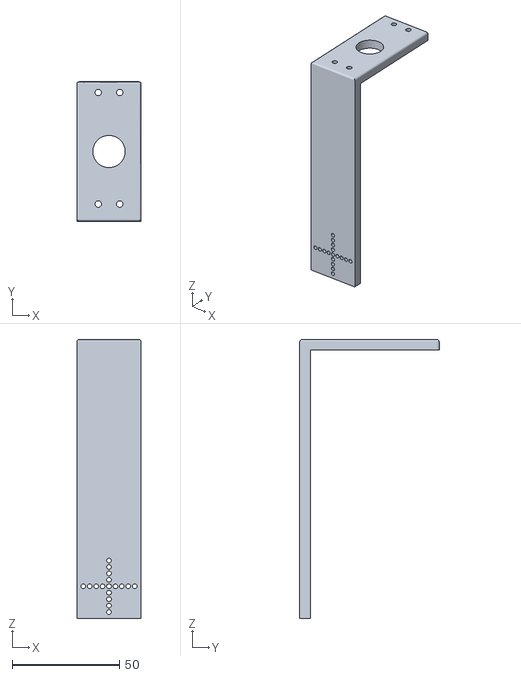
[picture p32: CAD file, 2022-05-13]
Design/CAD Model/Parts to Print/Arm/Link 2.stl
30.0 x 65.0 x 130.0

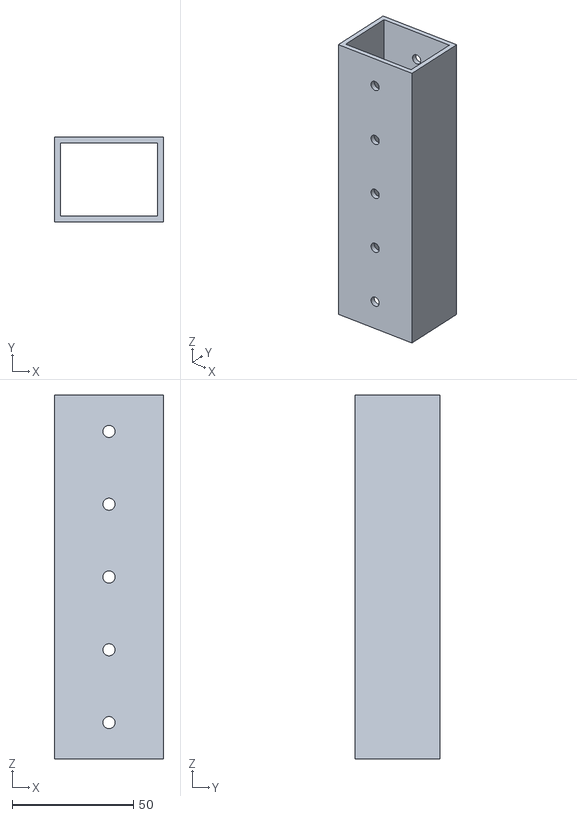
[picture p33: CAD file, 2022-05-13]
Design/CAD Model/Parts to Print/Camera Stand/Camera Base B.stl
45.0 x 35.0 x 150.0

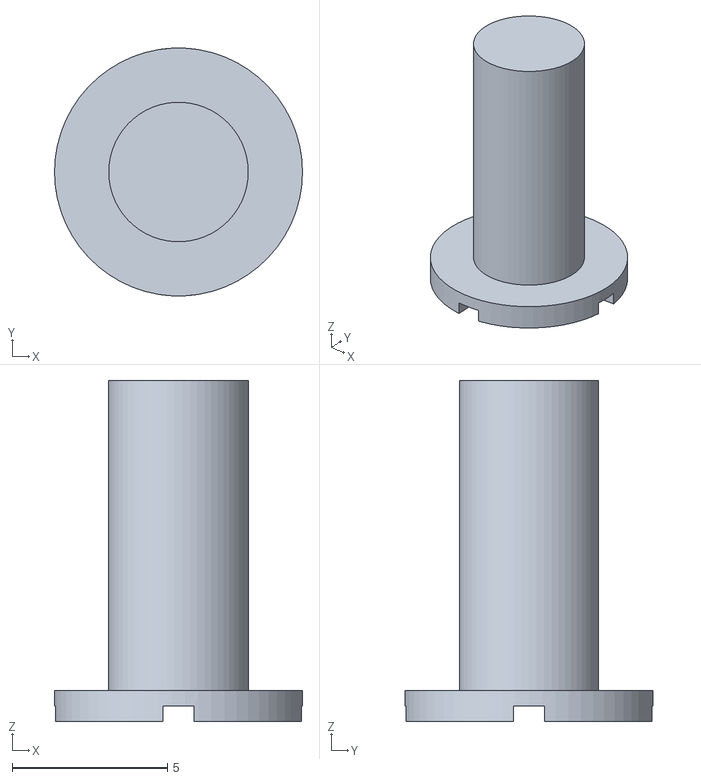
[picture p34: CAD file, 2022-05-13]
Design/CAD Model/CAD Final/Servo Link Pin.stl
8.00 x 7.99 x 11.0

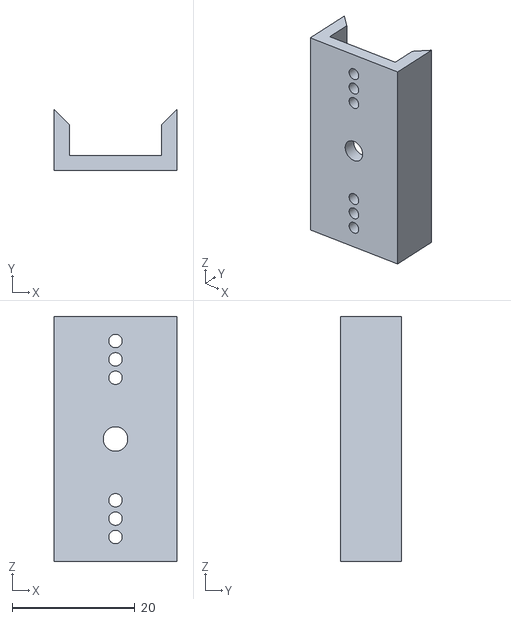
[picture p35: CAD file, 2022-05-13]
Design/CAD Model/Parts to Print - V3/End Effector Attachment.stl
20.0 x 10.0 x 40.0

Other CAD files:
Design/CAD Model/Parts to Print/Arm/Link 1.stl
Design/CAD Model/Parts to Print/Camera Stand/Camera Base C.stl
Design/CAD Model/CAD Final/Joint Servo.stl
Design/CAD Model/Parts to Print - V3/Link 1.stl
Design/CAD Model/CAD Final/Link 1.stl
Design/CAD Model/Parts to Print - V2/Base Main.stl
Design/CAD Model/Parts to Print - V2/Link 1.stl
Design/CAD Model/Parts to Print - V2/Link 2.stl
Design/CAD Model/Parts to Print/Arm/Base Slab (Raspberry Pi).stl

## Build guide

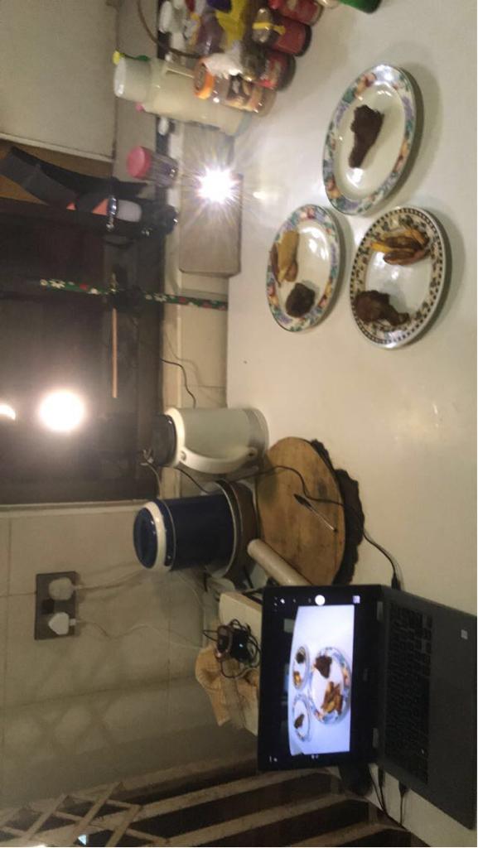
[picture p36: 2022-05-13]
Model Training/data collection setup.jpg

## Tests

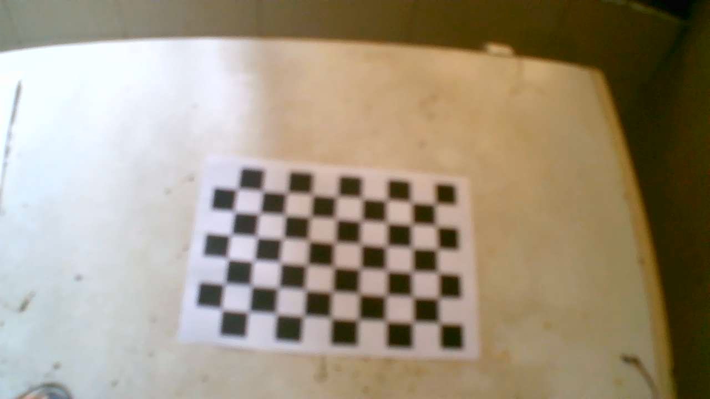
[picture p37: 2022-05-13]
Prototyping/Scripts/camera calibration images/WIN_20220427_16_52_15_Pro.jpg

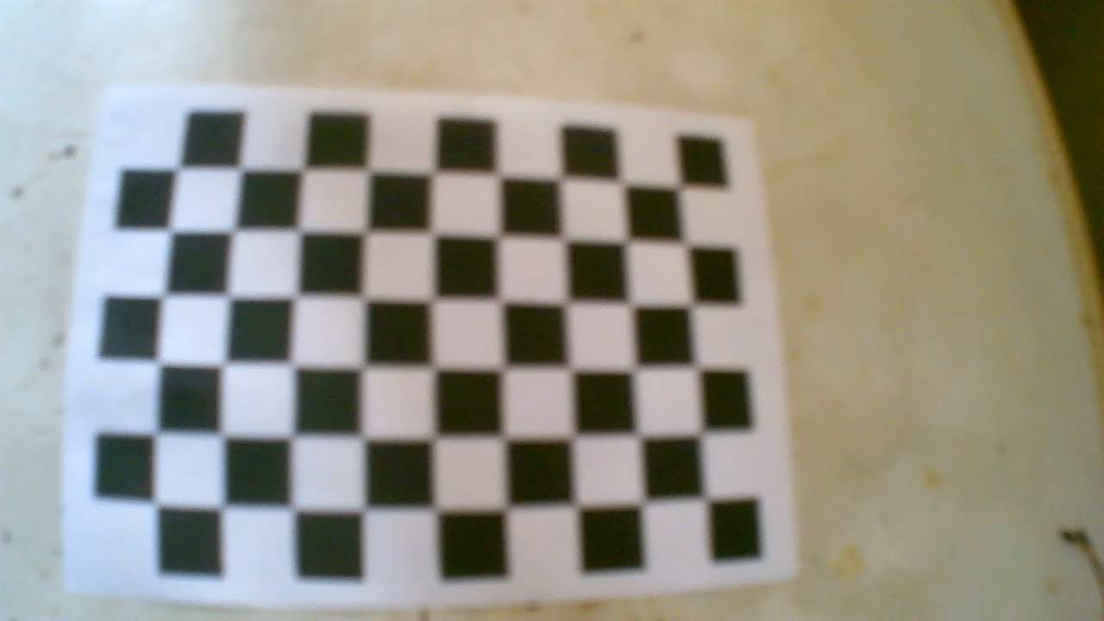
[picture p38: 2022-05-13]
Prototyping/Scripts/camera calibration images/WIN_20220427_16_59_05_Pro.jpg

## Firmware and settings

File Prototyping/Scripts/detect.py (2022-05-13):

import sys
import time

import cv2
from numpy import double
from object_detector import ObjectDetector
from object_detector import ObjectDetectorOptions
import utils


def run(model: str, camera_id: int, width: int, height: int, num_threads: int,
        score_threshold: float, enable_edgetpu: bool) -> None:

  # Variables to calculate FPS
  counter, fps = 0, 0
  start_time = time.time()

  # Start capturing video input from the camera
  cap = cv2.VideoCapture(camera_id)
  cap.set(cv2.CAP_PROP_FRAME_WIDTH, width)
  cap.set(cv2.CAP_PROP_FRAME_HEIGHT, height)

  # Visualization parameters
  row_size = 20  # pixels
  left_margin = 24  # pixels
  text_color = (0, 0, 255)  # red
  font_size = 1
  font_thickness = 1
  fps_avg_frame_count = 10

  # Initialize the object detection model
  options = ObjectDetectorOptions(
      num_threads=num_threads,
      score_threshold=score_threshold,
      max_results=3,
      enable_edgetpu=enable_edgetpu)
  detector = ObjectDetector(model_path=model, options=options)

  # Continuously capture images from the camera and run inference
  while cap.isOpened():
    success, image = cap.read()
    if not success:
      sys.exit('ERROR: Unable to read from webcam. Please verify your webcam settings.')

    counter += 1
    image = cv2.flip(image, 1)

    # Run object detection estimation using the model.
    rgb_image = cv2.cvtColor(image, cv2.COLOR_BGR2RGB)
    detections = detector.detect(rgb_image)

    # Draw keypoints and edges on input image
    image = utils.visualize(image, detections)

    # Calculate the FPS
    if counter % fps_avg_frame_count == 0:
      end_time = time.time()
      fps = fps_avg_frame_count / (end_time - start_time)
      start_time = time.time()

    # Show the FPS
    fps_text = 'FPS = {:.1f}'.format(fps)
    text_location = (left_margin, row_size)
    cv2.putText(image, fps_text, text_location, cv2.FONT_HERSHEY_PLAIN,
                font_size, text_color, font_thickness)

    # Stop the program if the ESC key is pressed.
    if cv2.waitKey(1) == 27:
      break
    cv2.imshow('object_detector', image)

  cap.release()
  cv2.destroyAllWindows()


def main():
  model_path = '/model_final.tflite'
  camera_id = 0
  frame_width = 300 # pixels
  frame_height = 250 # pixels
  num_threads = 4
  score_threshold = 0.3
  enable_edgetpu = False


  run(model_path, camera_id, frame_width, frame_height, num_threads, score_threshold, enable_edgetpu)


if __name__ == '__main__':
  main()

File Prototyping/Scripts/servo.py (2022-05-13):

import RPi.GPIO as GPIO
from time import sleep

class Servo:
    def __init__(self, gpio_pin=26, frequency=50):
        self.gpio_pin = gpio_pin
        self.frequency = frequency
        try:
            GPIO.setmode(GPIO.BCM)
            GPIO.setup(self.gpio_pin, GPIO.OUT)
            self.pwm = GPIO.PWM(self.gpio_pin, self.frequency)
            self.pwm.start(0)
            print(f'Servo at [GPIO pin {gpio_pin}] setup successfully')
        except Exception as e:
            print(f'ERROR: Servo setup unsuccessful - {e}')

    # Setters
    def setGpioPin(self, gpio_pin=26):
        self.gpio_pin = gpio_pin

    def setFrequency(self, frequency=50):
        self.frequency = frequency

    # Getters
    def getGpioPin(self):
        return self.gpio_pin

    def getFrequency(self):
        return self.frequency

    # Move sevrvo to a position
    def moveAngle(self, angle=0):
        if(angle<0 or angle>180):
            print('WARNING:Invalid angle. 0 <= angle <= 180 degrees\n')
        else:
            duty_cycle = (angle/20) + 2.5
            print(f'Moving to: Angle - {angle}   Duty Cycle - {duty_cycle}')
            GPIO.output(self.gpio_pin, True)
            self.pwm.ChangeDutyCycle(duty_cycle)
            sleep(1)
            GPIO.output(self.gpio_pin, False)
            self.pwm.ChangeDutyCycle(0)
            return angle
